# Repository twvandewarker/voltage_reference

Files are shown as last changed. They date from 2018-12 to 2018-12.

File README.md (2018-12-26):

# voltage_reference

If you want to see the EAGLE files, you'll probably need my parts library, located here: https://github.com/twvandewarker/eagle_library

Quick voltage standard based on MAX6341. Trimmable 4.096V output accurate within 1mV and divided to 1.9V and 190mV, precision resistors from 1.96ohm to 10Mohm, and current standards from 190uA to 14mA. It can be powered with a 12-24V wall wart or by batteries with a normal barrel jack. A 9V is pushing it, since the protection Schottky drops 0.4V, the LDO drops 0.5V, and the minimum input voltage of the MAX chip is 8V. The LDO's max input voltage is 26V.

The BOM for the parts I used is included, and the zip file is the one I sent to the fab house. I used JLCPCB.

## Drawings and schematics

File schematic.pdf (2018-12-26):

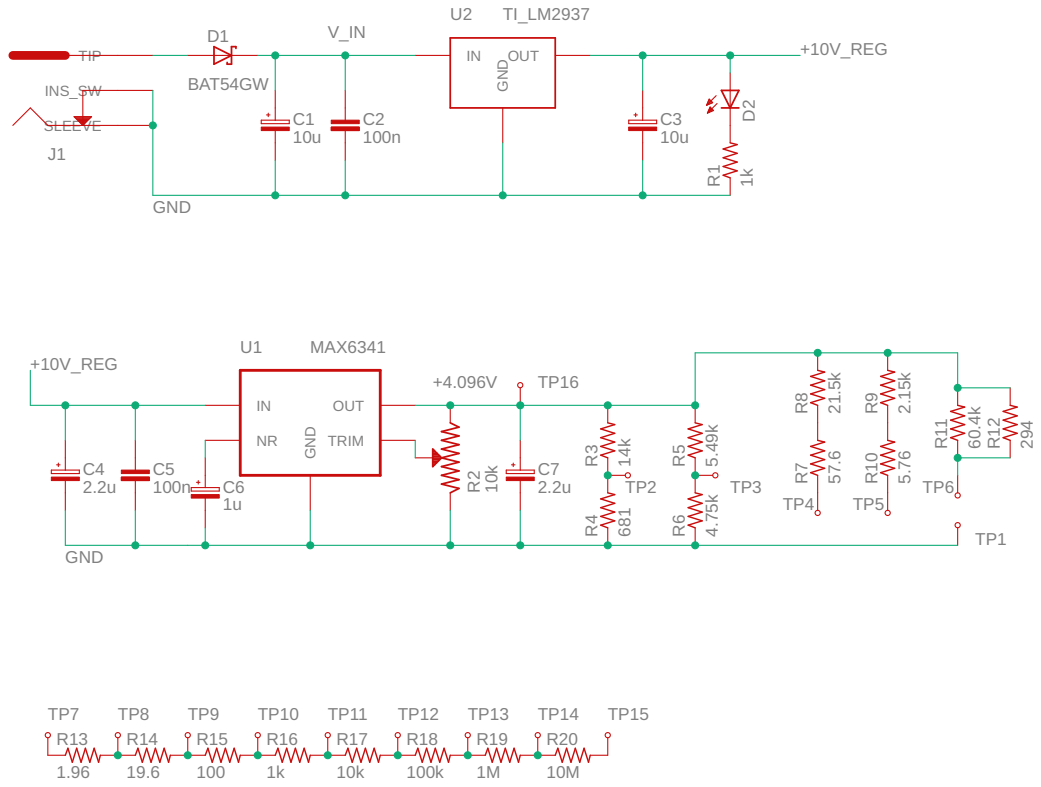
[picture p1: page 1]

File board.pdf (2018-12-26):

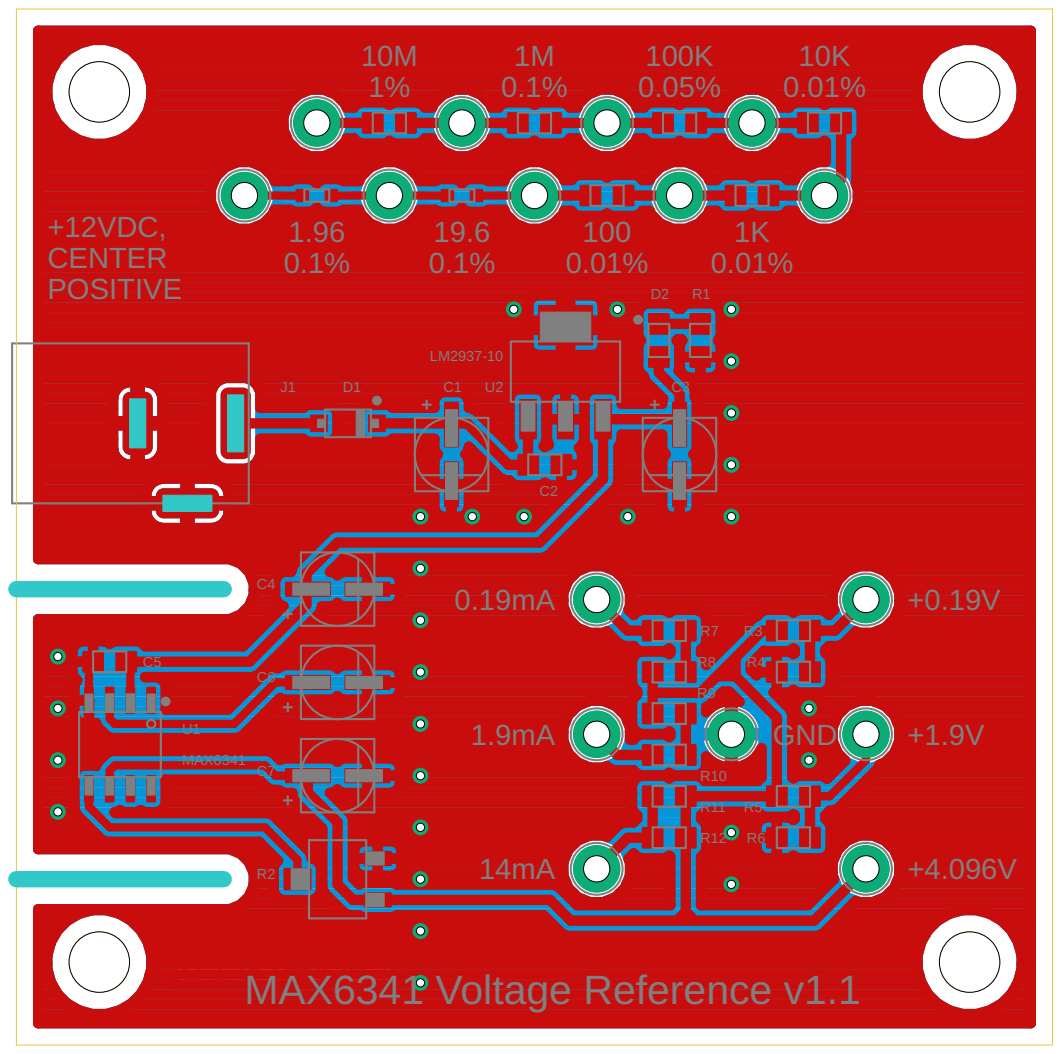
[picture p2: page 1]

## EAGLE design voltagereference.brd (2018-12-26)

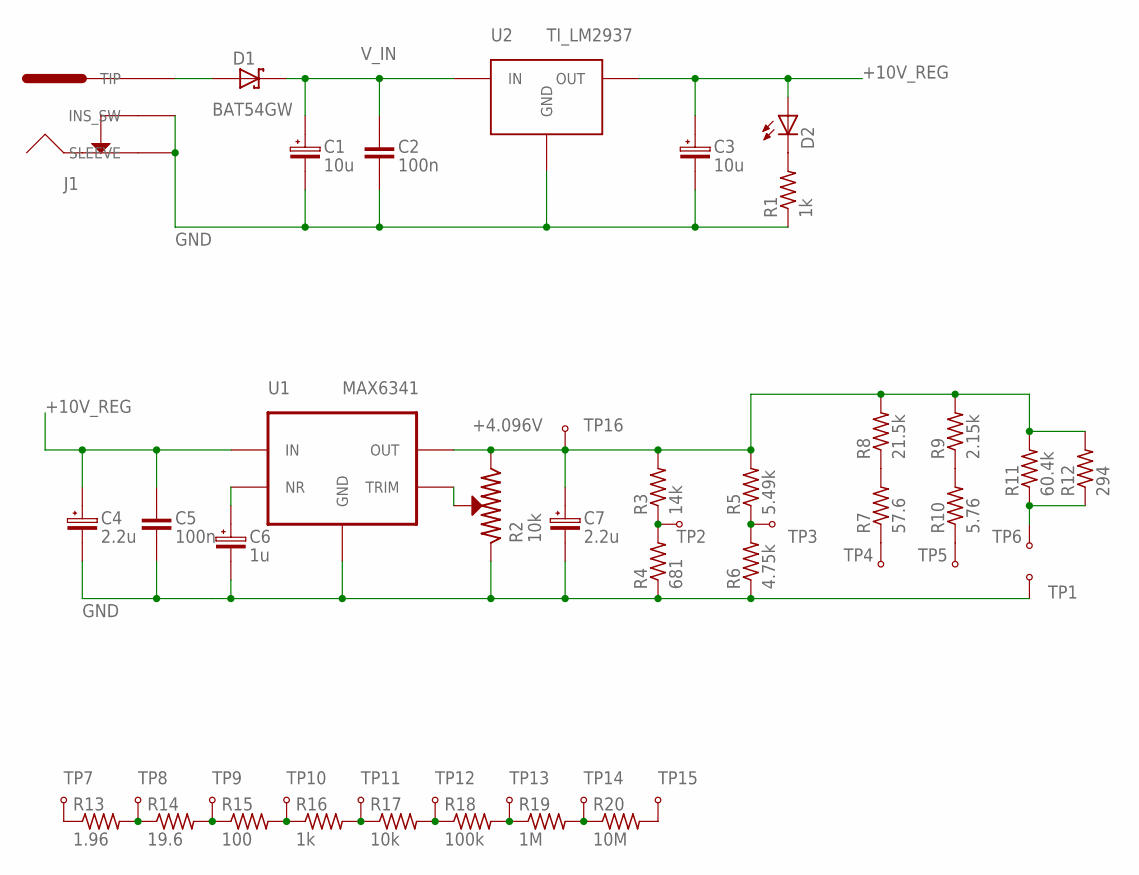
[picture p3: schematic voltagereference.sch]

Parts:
C1, C3: 10u; PANASONIC_EEE_4MM
C2, C5: 100n; 0805
C4, C7: 2.2u; PANASONIC_EEE_4MM
C6: 1u; PANASONIC_EEE_4MM
D1: BAT54GW; SOD123_NEX
D2: LED_0805; 0805_POL
J1: KOBICONN_163-179PH-EX
R1, R16: 1k; 0805
R2: 10k; BOURNS_3224X
R3: 14k; 0805
R4: 681; 0805
R5: 5.49k; 0805
R6: 4.75k; 0805
R7: 57.6; 0805
R8: 21.5k; 0805
R9: 2.15k; 0805
R10: 5.76; 0805
R11: 60.4k; 0805
R12: 294; 0805
R13: 1.96; 0603
R14: 19.6; 0603
R15: 100; 0805
R17: 10k; 0805
R18: 100k; 0805
R19: 1M; 0805
R20: 10M; 0805
TP1, TP2, TP3, TP4, TP5, TP6, TP7, TP8, TP9, TP10, TP11, TP12, TP13, TP14, TP15, TP16: KEYSTONE_500X
U1: MAX6341; SO8_MAX
U2: TI_LM2937; SOT223_TI

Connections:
0.19MA: R7.P$1 (1), TP4.P$1
1.9MA: R10.P$1 (1), TP5.P$1
14MA: R11.P$1 (1), R12.P$1 (1), TP6.P$1
+0.19V: R3.P$1 (1), R4.P$2 (2), TP2.P$1
+1.9V: R5.P$1 (1), R6.P$2 (2), TP3.P$1
+4.096V: C7.P$1 (1), R2.P$1 (1), R3.P$2 (2), R5.P$2 (2), R8.P$2 (2), R9.P$2 (2), R11.P$2 (2), R12.P$2 (2), TP16.P$1, U1.P$6 (OUT)
+10V_REG: C3.P$1 (1), C4.P$1 (1), C5.P$1 (1), D2.P$1 (A), U1.P$2 (IN), U2.P$3 (OUT)
GND: C1.P$2 (2), C2.P$2 (2), C3.P$2 (2), C4.P$2 (2), C5.P$2 (2), C6.P$2 (2), C7.P$2 (2), J1.P$2 (SLEEVE), J1.P$3 (INS_SW), J1.P$5 (SLEEVE), J1.P$6 (INS_SW), R1.P$1 (1), R2.P$3 (3), R4.P$1 (1), R6.P$1 (1), TP1.P$1, U1.P$4 (GND), U2.P$2 (GND), U2.P$4 (GND)
unnamed: D2.P$2 (C), R1.P$2 (2)
unnamed: R7.P$2 (2), R8.P$1 (1)
unnamed: R9.P$1 (1), R10.P$2 (2)
unnamed: R13.P$2 (2), R14.P$1 (1), TP8.P$1
unnamed: R14.P$2 (2), R15.P$1 (1), TP9.P$1
unnamed: R15.P$2 (2), R16.P$1 (1), TP10.P$1
unnamed: R16.P$2 (2), R17.P$1 (1), TP11.P$1
unnamed: R17.P$2 (2), R18.P$1 (1), TP12.P$1
unnamed: R18.P$2 (2), R19.P$1 (1), TP13.P$1
unnamed: R19.P$2 (2), R20.P$1 (1), TP14.P$1
unnamed: R13.P$1 (1), TP7.P$1
unnamed: R20.P$2 (2), TP15.P$1
NR: C6.P$1 (1), U1.P$3 (NR)
TIP: D1.P$1 (A), J1.P$1 (TIP), J1.P$4 (TIP)
TRIM: R2.P$2 (2), U1.P$5 (TRIM)
V_IN: C1.P$1 (1), C2.P$1 (1), D1.P$2 (C), U2.P$1 (IN)

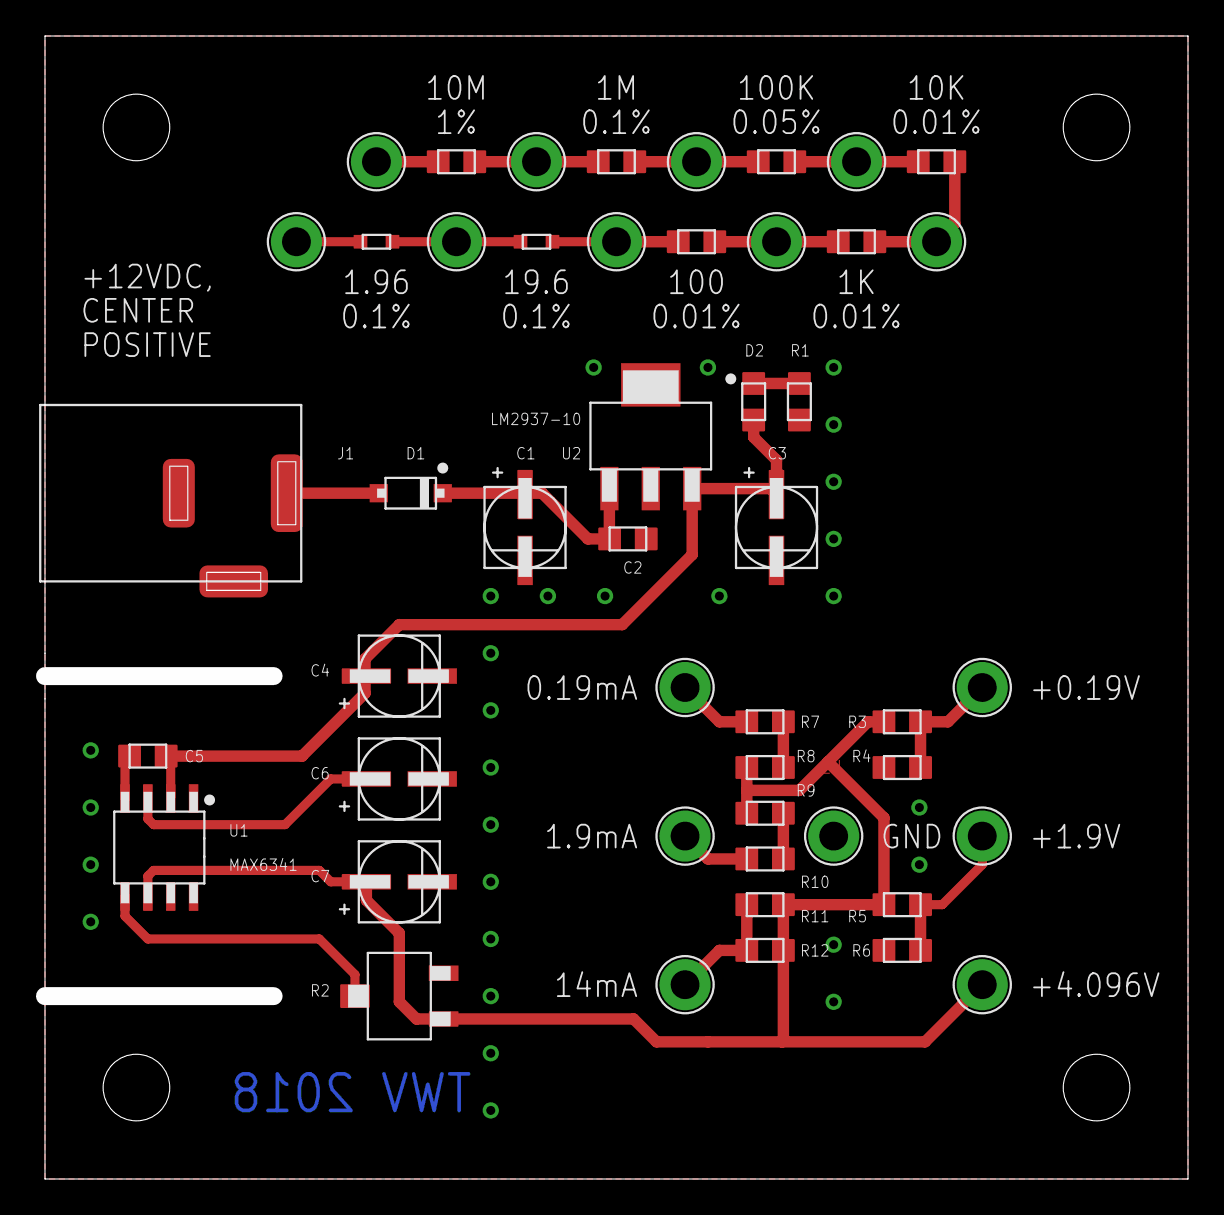
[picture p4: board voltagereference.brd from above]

Board: 2 copper layers, 63.5 x 63.5 mm, 48 parts (0 on the bottom side), 24 nets.
